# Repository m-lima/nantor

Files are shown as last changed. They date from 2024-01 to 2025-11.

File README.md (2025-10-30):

# Nantor

A wireless 42-key split keyboard made for Kailh Choc switches.

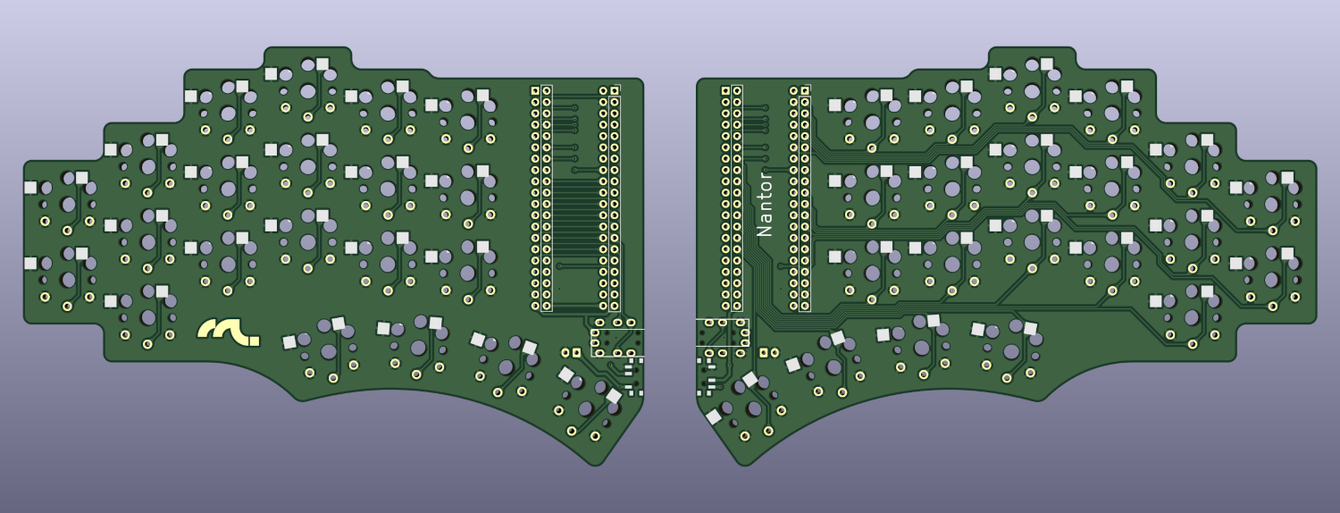
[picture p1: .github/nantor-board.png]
Nantor Board


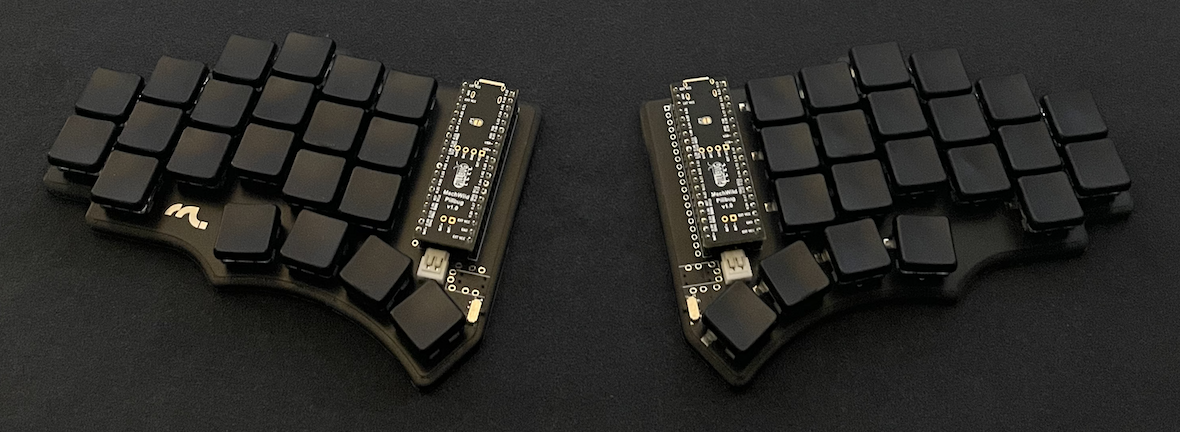
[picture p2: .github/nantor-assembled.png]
Nantor


**Features**

- Flippable design
- [PillBug] support
- [BlackPill] support
- Wired and wireless support
- Battery power support
- Hotswap switches support

## Hardware

The board was designed with [KiCad] and can be found in [board/kicad](board/kicad).

The gerber files can be found in [board/kicad/gerber](board/kicad/gerber).

## ZMK

For wireless and wired mode. This firmware assumes that [PillBug] is being used.

> [!TIP]
>
> This is the latest and recommended configuration.

### Layout

> [!NOTE]
>
> Definition available at [zmk/shared/config/boards/shields/nantor/nantor.keymap](zmk/shared/config/boards/shields/nantor/nantor.keymap)

#### Base (colemak)

```
            ╭───╮                     ╭───╮
        ╭───┤ F ├───┬───╮     ╭───┬───┤ U ├───╮
    ╭───┤ W ├───┤ P │ B │     │ J │ L ├───┤ Y ├───╮
╭───┤ Q ├───┤ S ├───┼───┤     ├───┼───┤ E ├───┤ ; ├───╮
│Esc├───┤ R ├───┤ T │ G │     │ M │ N ├───┤ I ├───┤ ' │
├───┤ A ├───┤ C ├───┼───┤     ├───┼───┤ , ├───┤ O ├───┤
│Alt├───┤ X ├───┤ D │ V │     │ K │ H ├───┤ . ├───┤ \ │
╰───┤ Z ├───┘   ╰───┴───╯     ╰───┴───╯   ╰───┤ / ├───╯
    ╰───╯     ╭───┬───╮         ╭───┬───╮     ╰───╯
          ╭───┤Spc│Sft├───╮ ╭───┤NUM│Ent├───╮
          │Bsp├───┴───┤ ⌘ │ │Ctl├───┴───┤FNS│
          ╰───╯       ╰───╯ ╰───╯       ╰───╯
```

#### Base (qwerty)

```
            ╭───╮                     ╭───╮
        ╭───┤ E ├───┬───╮     ╭───┬───┤ I ├───╮
    ╭───┤ W ├───┤ R │ T │     │ Y │ U ├───┤ O ├───╮
╭───┤ Q ├───┤ D ├───┼───┤     ├───┼───┤ K ├───┤ P ├───╮
│Esc├───┤ S ├───┤ F │ G │     │ H │ J ├───┤ L ├───┤ ' │
├───┤ A ├───┤ C ├───┼───┤     ├───┼───┤ , ├───┤ ; ├───┤
│Alt├───┤ X ├───┤ V │ B │     │ N │ M ├───┤ . ├───┤ \ │
╰───┤ Z ├───┘   ╰───┴───╯     ╰───┴───╯   ╰───┤ / ├───╯
    ╰───╯     ╭───┬───╮         ╭───┬───╮     ╰───╯
          ╭───┤Spc│Sft├───╮ ╭───┤NUM│Ent├───╮
          │Bsp├───┴───┤ ⌘ │ │Ctl├───┴───┤FNS│
          ╰───╯       ╰───╯ ╰───╯       ╰───╯
```

#### Numbers

```
            ╭───╮                     ╭───╮
        ╭───┤ 8 ├───┬───╮     ╭───┬───┤PUp├───╮
    ╭───┤ 7 ├───┤ 9 │ 0 │     │Hom│PDn├───┤End├───╮
╭───┤ = ├───┤ 5 ├───┼───┤     ├───┼───┤ ↑ ├───┤Sft├───╮
│Esc├───┤ 4 ├───┤ 6 │ [ │     │ ← │ ↓ ├───┤ → ├───┤Ctl│
├───┤ - ├───┤ 2 ├───┼───┤     ├───┼───┤ , ├───┤ ⌘ ├───┤
│Alt├───┤ 1 ├───┤ 3 │ ] │     │Del│Tab├───┤ . ├───┤Alt│
╰───┤ ` ├───┘   ╰───┴───╯     ╰───┴───╯   ╰───┤ / ├───╯
    ╰───╯     ╭───┬───╮         ╭───┬───╮     ╰───╯
          ╭───┤Spc│Sft├───╮ ╭───┤ ∆ │Ent├───╮
          │Bsp├───┴───┤ ⌘ │ │Ctl├───┴───┤CFG│
          ╰───╯       ╰───╯ ╰───╯       ╰───╯
```

#### Functions

```
            ╭───╮                     ╭───╮
        ╭───┤F10├───┬───╮     ╭───┬───┤+B ├───╮
    ╭───┤ F9├───┤F11│F12│     │   │-B ├───┤   ├───╮
╭───┤Ins├───┤ F6├───┼───┤     ├───┼───┤ ‖ ├───┤Sft├───╮
│Esc├───┤ F5├───┤ F7│ F8│     │   │ ◄ ├───┤ ► ├───┤Ctl│
├───┤Cap├───┤ F2├───┼───┤     ├───┼───┤ V0├───┤ ⌘ ├───┤
│Alt├───┤ F1├───┤ F3│ F4│     │   │-V ├───┤+V ├───┤Alt│
╰───┤PSc├───┘   ╰───┴───╯     ╰───┴───╯   ╰───┤   ├───╯
    ╰───╯     ╭───┬───╮         ╭───┬───╮     ╰───╯
          ╭───┤Spc│Sft├───╮ ╭───┤CFG│Ent├───╮
          │Bsp├───┴───┤ ⌘ │ │Ctl├───┴───┤ ∆ │
          ╰───╯       ╰───╯ ╰───╯       ╰───╯
```

#### Config

```
            ╭───╮                     ╭───╮
        ╭───┤   ├───┬───╮     ╭───┬───┤   ├───╮
    ╭───┤   ├───┤   │BTC│     │   │   ├───┤   ├───╮
╭───┤   ├───┤BT4├───┼───┤     ├───┼───┤   ├───┤   ├───╮
│   ├───┤BT3├───┤   │   │     │   │   ├───┤   ├───┤CLM│
├───┤BLE├───┤BT1├───┼───┤     ├───┼───┤   ├───┤   ├───┤
│   ├───┤BT0├───┤BT2│   │     │   │   ├───┤   ├───┤QWT│
╰───┤USB├───┘   ╰───┴───╯     ╰───┴───╯   ╰───┤   ├───╯
    ╰───╯     ╭───┬───╮         ╭───┬───╮     ╰───╯
          ╭───┤   │   ├───╮ ╭───┤ ∆ │ ᛒ ├───╮
          │   ├───┴───┤   │ │ ⌁ ├───┴───┤ ∆ │
          ╰───╯       ╰───╯ ╰───╯       ╰───╯
```

### LED encoding

> [!NOTE]
>
> This is assuming that the board being used is the PillBug (nRF52840)

> [!NOTE]
>
> In this section, a low frequency means a 500ms period, while high frequency means a 250ms period

#### Battery

If no charge is detected, all LEDs will blink at a low frequency.
Similarly, when at 100% charge, all LEDs will blink at a high frequency.
For all other values, the LEDs will encode the charge as such:

| Charge | Bottom | Center | Top  |
| --- | --- | --- | ---- |
| None | Low | Low | Low  |
| < 10%  | Low | Off | Off  |
| < 20%  | High | Off | Off  |
| < 30%  | Full | Off | Off  |
| < 40%  | Full | Low | Off  |
| < 50%  | Full | High | Off  |
| < 60%  | Full | Full | Off  |
| < 70%  | Full | Full | Low  |
| < 80%  | Full | Full | High |
| < 90%  | Full | Full | Full |
| > 90%  | High | High | High |

#### Bluetooth

The left side LEDs will encode the currently active channel in binary with the bottom LED being the least significant bit.
For a stable connection, the LEDs will stay fully on.
When open for connections, they will blink at a high frequency.
Lastly, when disconnected, they will blink at a low frequency.

### Flashing

> [!NOTE]
>
> This is assuming that the board being used is the PillBug (nRF52840)

1. [Build the images](#build-the-images)
2. [Enter UF2 mode](#enter-uf2-mode)
3. [Load the images](#load-the-images)

#### Build the images

```bash
$ ./zmk/build.sh make p
```

> [!NOTE]
>
> The above command will do a pristine build. Check [zmk/build.sh](zmk/build.sh) for more options.

The output files will be located at `zmk/shared/build/(left|right)/zephyr/zmk.uf2`.

#### Enter UF2 mode

1. Connect the USB cable
2. Reset twice. To reset, either press the reset button or pull the `RST` pin down to `GND`
3. The board should show up as a storage device

#### Load the images

The board should be available as a USB storage device. Copy the `zmk/shared/build/(left|right)/zephyr/zmk.uf2` files to this new device. It should flash and reset automatically.

## QMK

For wired mode. This firmware assumes that [BlackPill] is being used.

> [!WARNING]
>
> This is the first version of **Nantor** and is no longer actively maintained.

[PillBug]: https://mechwild.com/product/pillbug
[BlackPill]: https://stm32-base.org/boards/STM32F103C8T6-Black-Pill.html
[KiCad]: https://www.kicad.org

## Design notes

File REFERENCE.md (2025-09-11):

# References

## Documentation for pins on the Blackpill
[https://docs.qmk.fm/platformdev_blackpill_f4x1](https://docs.qmk.fm/platformdev_blackpill_f4x1)

## Reference for adding ZMK code

### RGB LED

[https://github.com/caksoylar/zmk-rgbled-widget](https://github.com/caksoylar/zmk-rgbled-widget)

### Leader key
[https://github.com/urob/zmk-leader-key](https://github.com/urob/zmk-leader-key)

### Module creation
[https://zmk.dev/docs/development/module-creation](https://zmk.dev/docs/development/module-creation)

### New behavior
[https://zmk.dev/docs/development/new-behavior](https://zmk.dev/docs/development/new-behavior)

### Device tree source syntax
[https://docs.zephyrproject.org/3.5.0/build/dts/bindings-syntax.html](https://docs.zephyrproject.org/3.5.0/build/dts/bindings-syntax.html)

### ZMK
[https://github.com/zmkfirmware/zmk](https://github.com/zmkfirmware/zmk)

### Zephyr
[https://github.com/zephyrproject-rtos/zephyr](https://github.com/zephyrproject-rtos/zephyr)

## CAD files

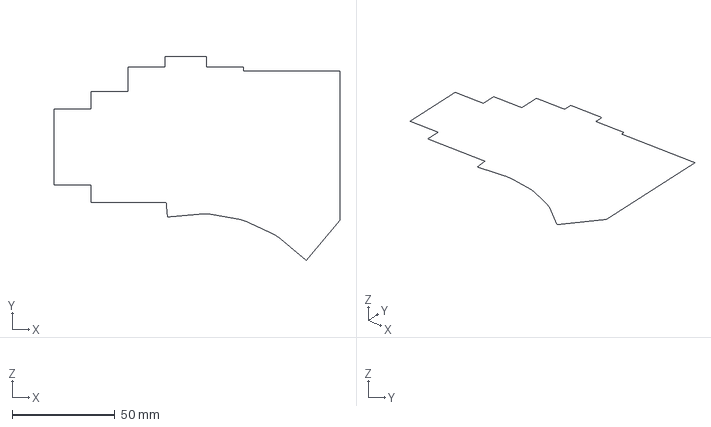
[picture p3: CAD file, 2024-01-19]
board/freecad/cadded.FCStd
139.0 x 99.1 x 0 mm

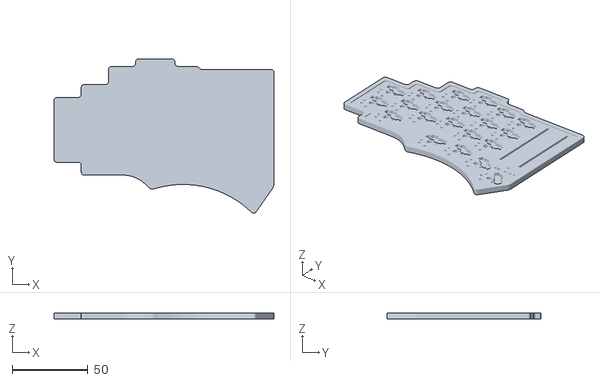
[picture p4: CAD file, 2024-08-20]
case/blender/case.stl
145.5 x 102.2 x 3.80

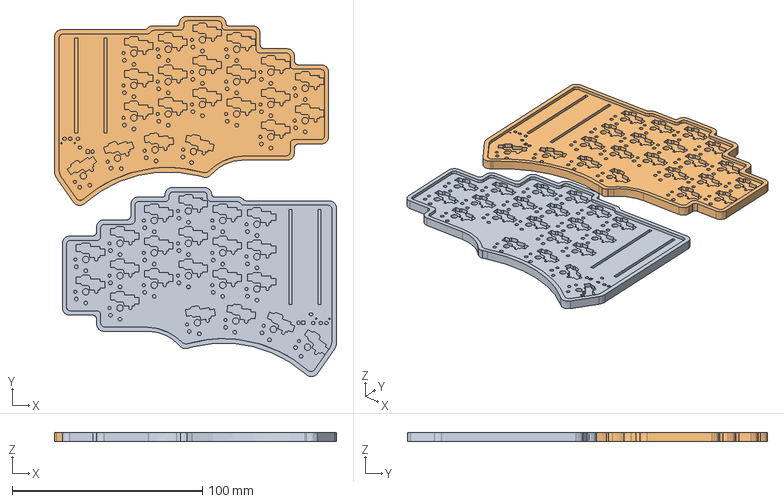
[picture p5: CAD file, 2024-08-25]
case/freecad/case_simple.FCStd
148.3 x 189.4 x 4.60 mm
left
right

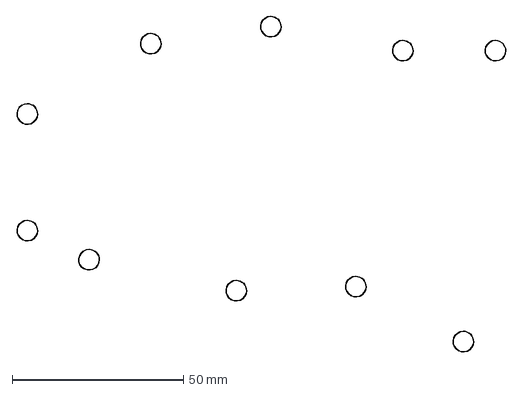
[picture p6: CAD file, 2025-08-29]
case/freecad/sources/v2/feet.dxf
142.8 x 98.1 mm

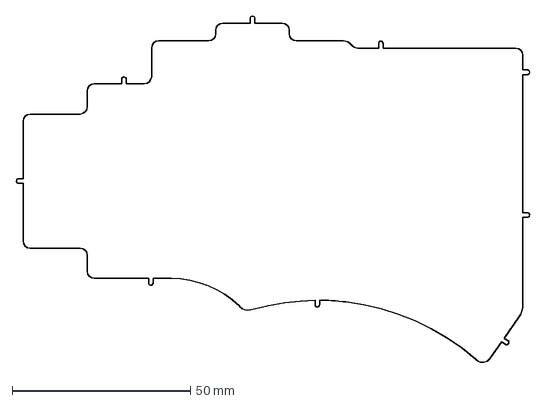
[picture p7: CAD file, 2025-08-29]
case/fusion/sources/walls.dxf
143.9 x 97.4 mm

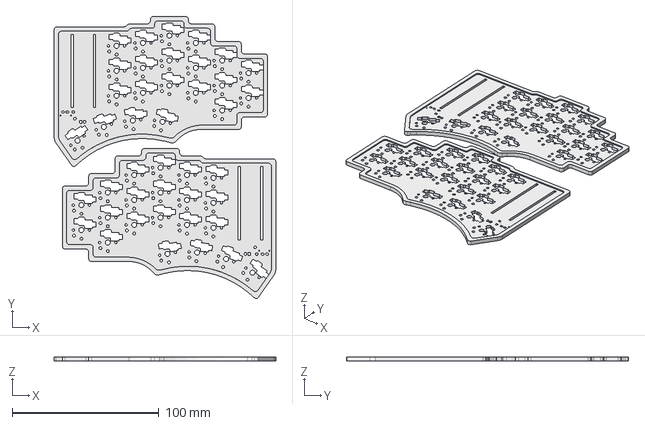
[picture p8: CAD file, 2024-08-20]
case/freecad/case_test.FCStd
151.1 x 192.2 x 2.80 mm

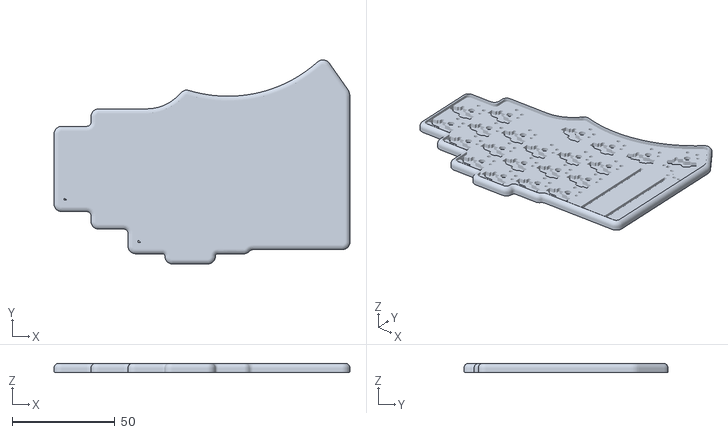
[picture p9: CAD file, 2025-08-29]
case/freecad/sources/v2/nantor_right.stl
144.1 x 99.4 x 4.60

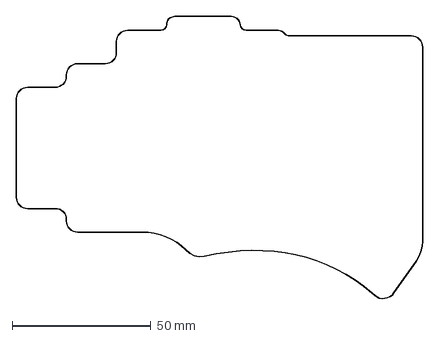
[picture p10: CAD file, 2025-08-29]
case/fusion/sources/case_base.dxf
146.1 x 101.8 mm

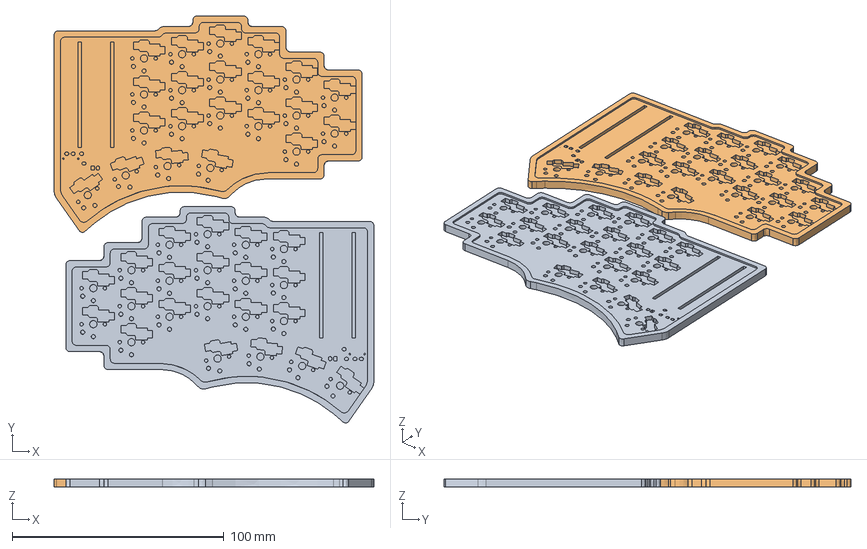
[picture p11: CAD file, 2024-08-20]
case/freecad/case.FCStd
151.1 x 192.2 x 3.80 mm
left
right (Mirror #1)

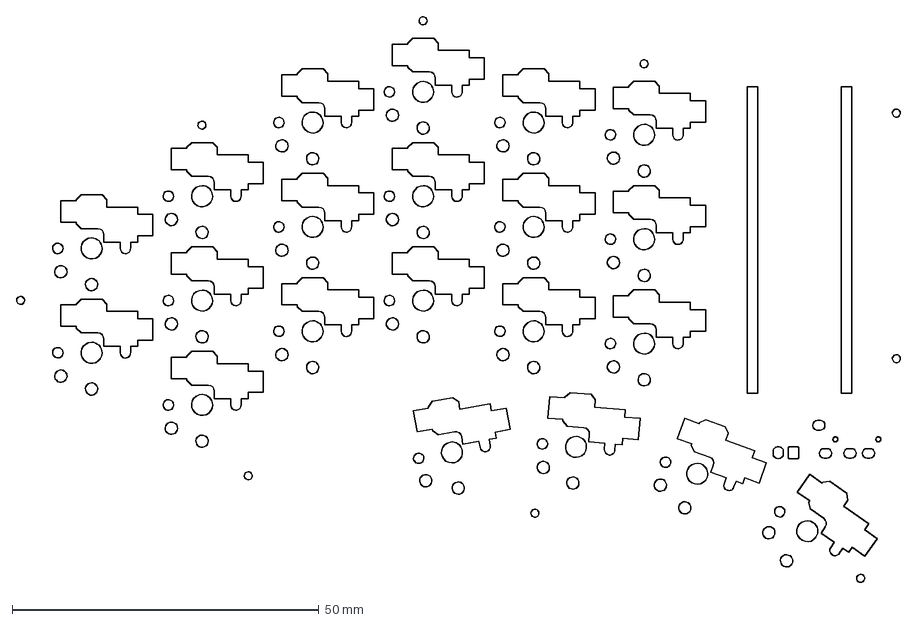
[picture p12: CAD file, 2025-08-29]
case/fusion/sources/wells_top_left.dxf
144.0 x 92.2 mm

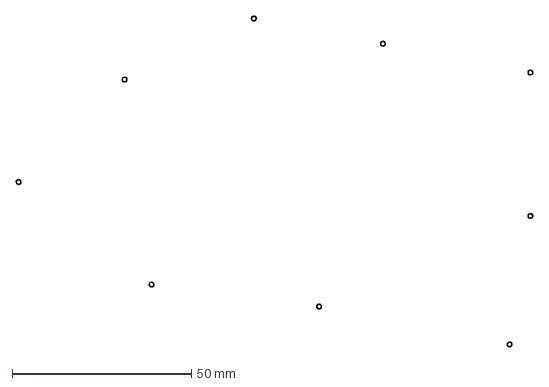
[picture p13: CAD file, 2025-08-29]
case/fusion/sources/holes_thru.dxf
144.0 x 92.2 mm

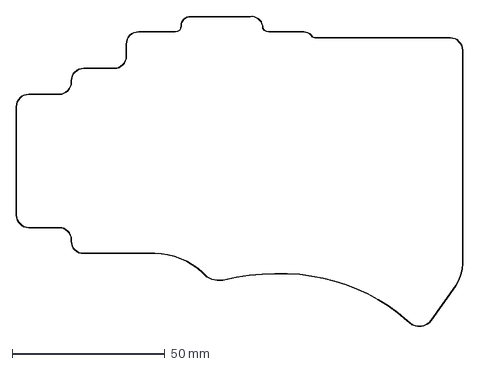
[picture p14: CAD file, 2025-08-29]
case/fusion/sources/case_base_line.dxf
146.1 x 101.8 mm

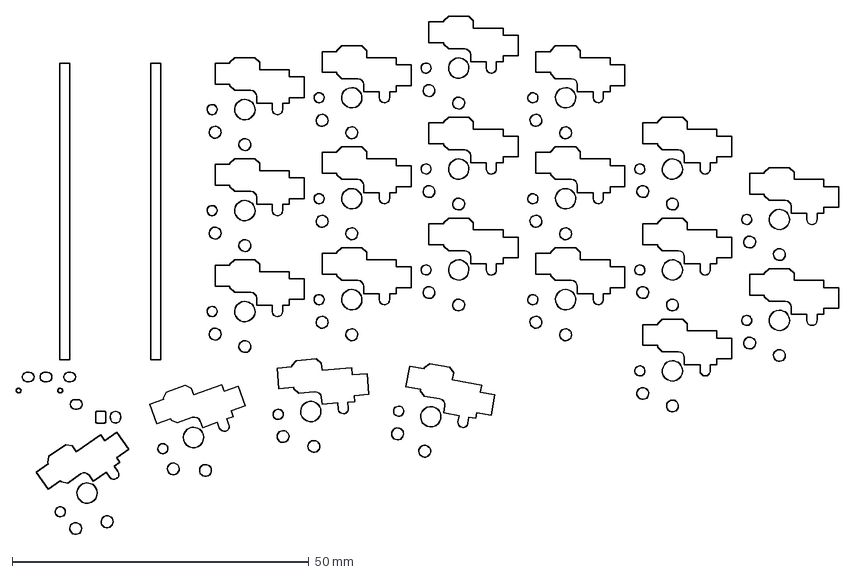
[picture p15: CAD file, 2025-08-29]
case/freecad/sources/v2/wells_right.dxf
138.5 x 87.3 mm

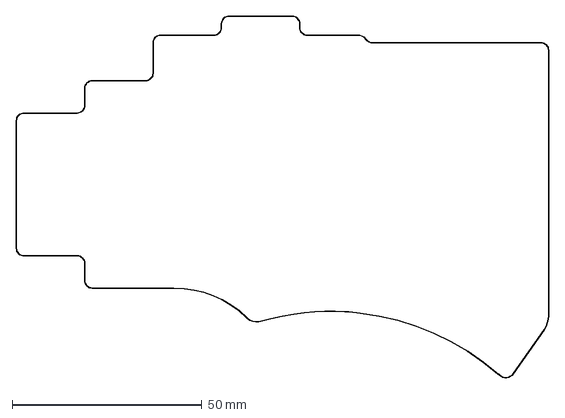
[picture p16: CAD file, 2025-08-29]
case/fusion/sources/case_hole.dxf
140.1 x 95.2 mm

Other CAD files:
case/freecad/sources/v2/nantor_left_tolerance.stl
case/freecad/sources/v2/nantor_right_tolerance.stl
case/freecad/sources/v2/nantor_left.stl
case/freecad/sources/v2/inner_bounds.dxf
case/freecad/sources/v2/bounds.dxf
case/freecad/sources/v2/feet_tolerance.dxf
case/freecad/sources/v2/inner_bounds_tolerance.dxf
case/freecad/sources/v2/inner_bounds_wire.dxf
case/freecad/sources/v2/nantor.stl
case/freecad/sources/v2/nantor_tolerance.stl
case/freecad/sources/v2/wells_left.dxf
case/fusion/nantor v3.f3d
case/fusion/nantor_tolerance v2.f3d
case/fusion/nantor_with_screws v2.f3d
case/fusion/sources/case_top.dxf
case/fusion/sources/hex.dxf
case/fusion/sources/wall_holes_bottom.dxf
case/fusion/sources/wells_bottom.dxf

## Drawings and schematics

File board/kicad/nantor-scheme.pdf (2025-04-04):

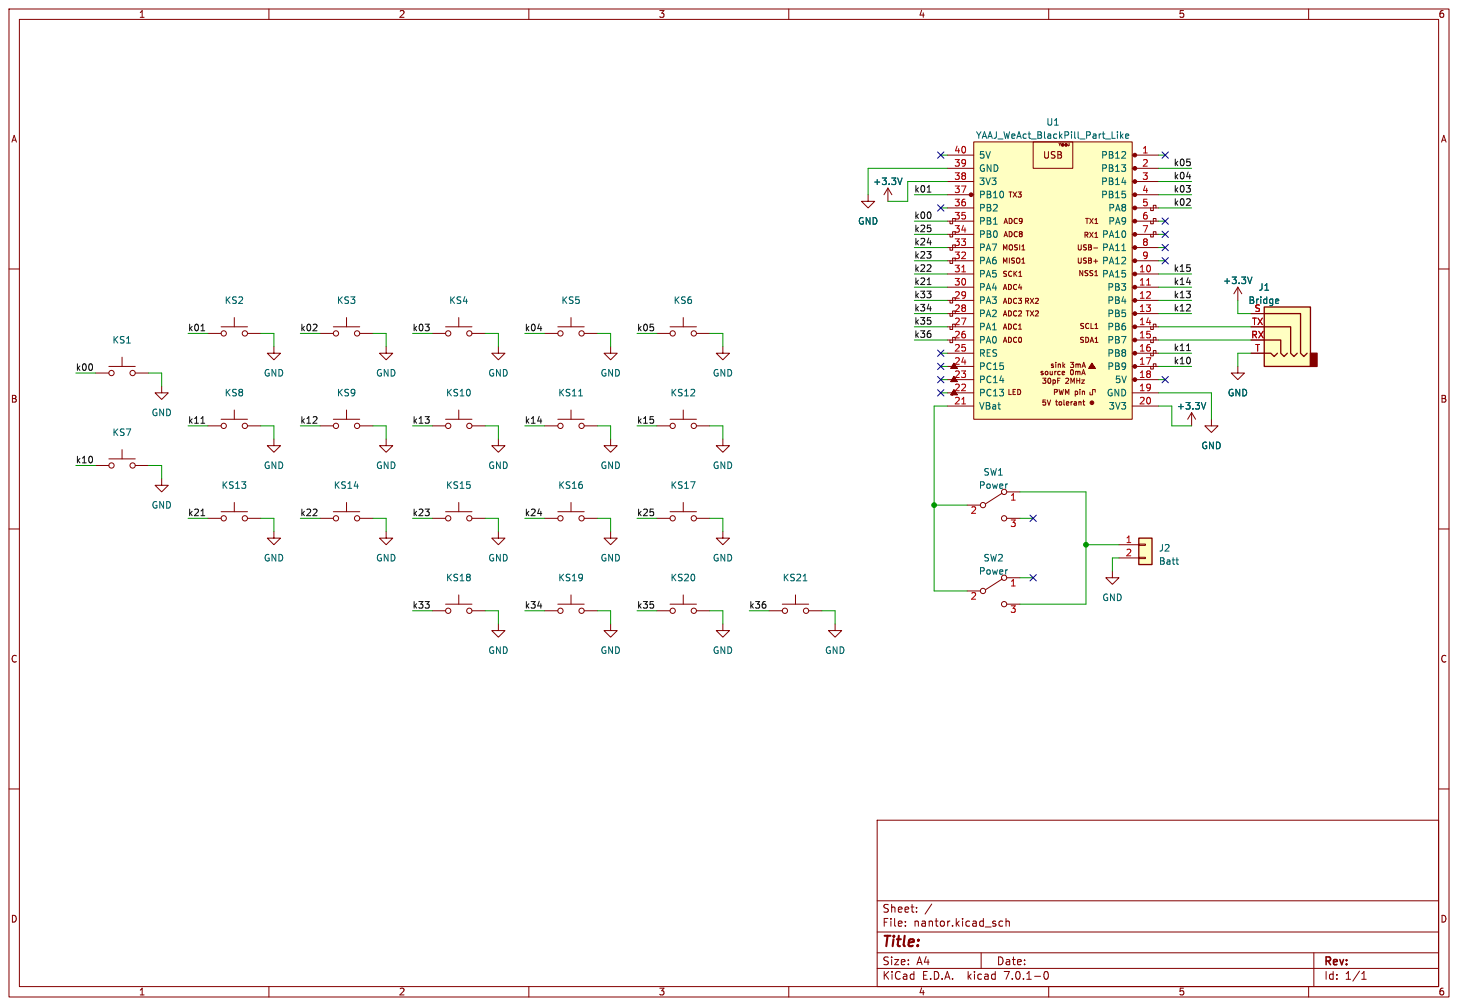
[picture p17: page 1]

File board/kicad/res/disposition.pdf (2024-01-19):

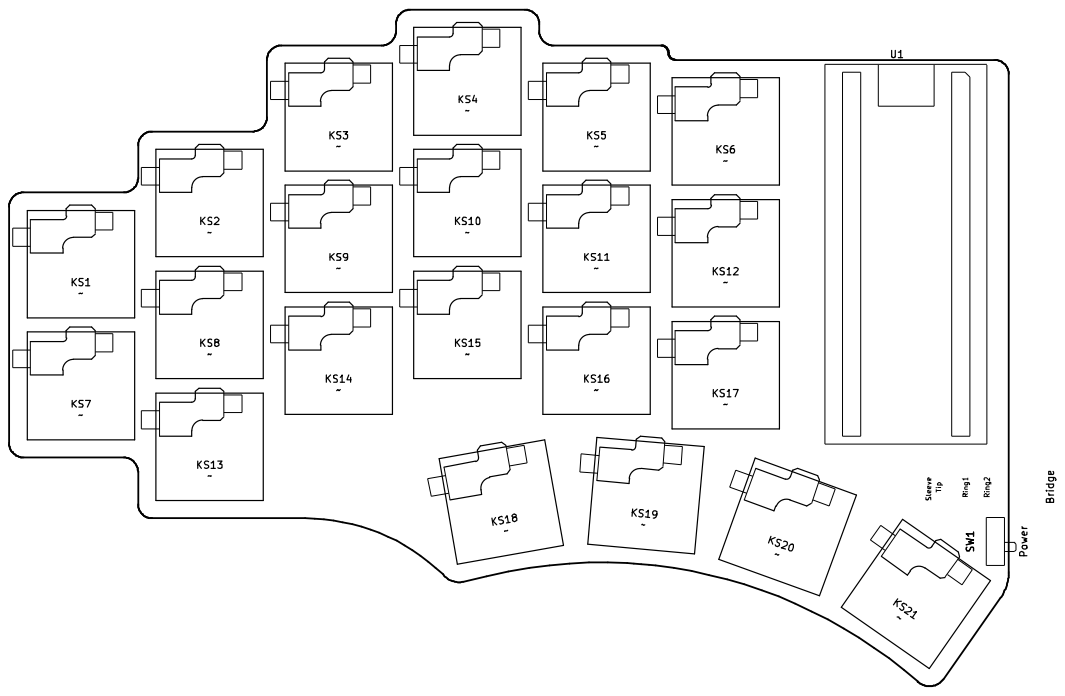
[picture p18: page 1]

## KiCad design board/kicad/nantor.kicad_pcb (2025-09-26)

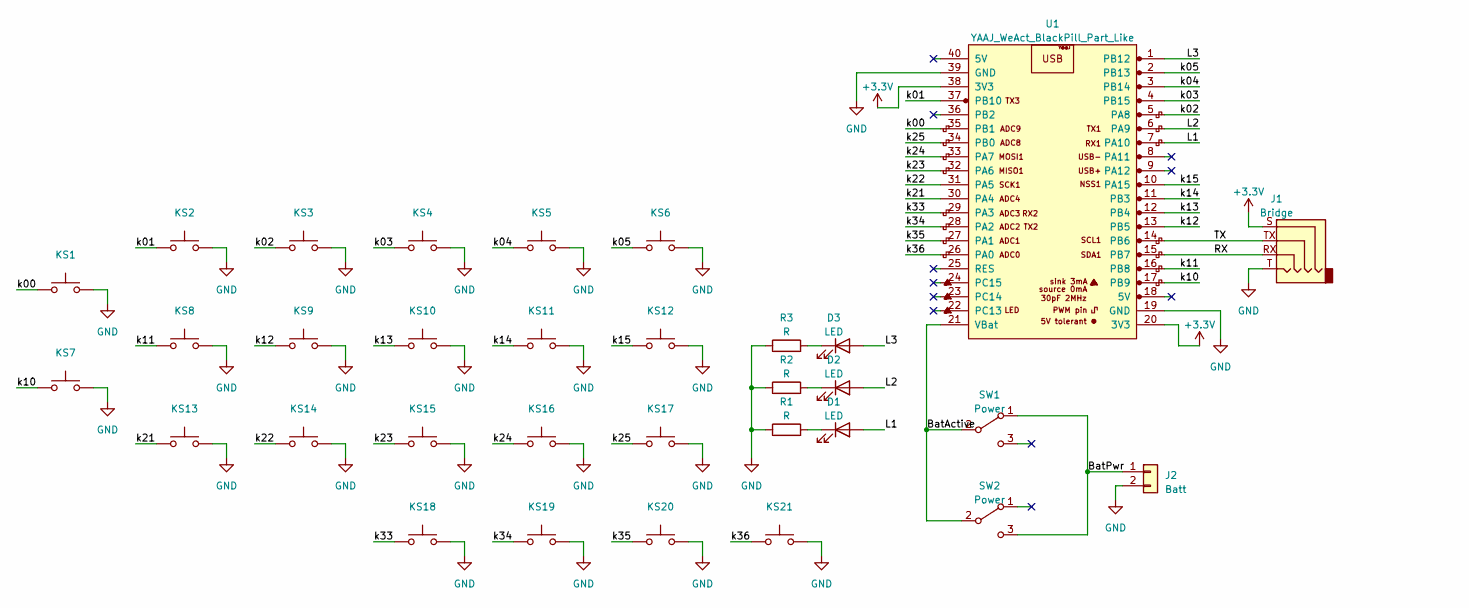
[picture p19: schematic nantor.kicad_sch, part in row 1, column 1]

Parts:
D1, D2, D3: LED; LED_0805
J1: Bridge; TRRS-PJ-320A
J2: Batt; JST_EH_S2B-EH_1x02_P2.50mm_Horizontal
KS1, KS2, KS3, KS4, KS5, KS6, KS7, KS8, KS9, KS10, KS11, KS12, KS13, KS14, KS15, KS16, KS17, KS18, KS19, KS20, KS21: Kailh_socket_PG1350_optional_reversible_clean
R1, R2, R3: R; LED_0805
SW1, SW2: Power; SW_SPDT_PCM12
U1: YAAJ_WeAct_BlackPill_Part_Like; BlackPill

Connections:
+3.3V: J1.S, U1.20 (3V3), U1.38 (3V3)
/BatActive: SW1.2 (B), SW2.2 (B), U1.21 (VBat)
/BatPwr: J2.1, SW1.1 (A), SW2.3 (C)
/L1: D1.2 (A), U1.7 (PA10)
/L2: D2.2 (A), U1.6 (PA9)
/L3: D3.2 (A), U1.1 (PB12)
/RX: J1.RX, U1.15 (PB7)
/TX: J1.TX, U1.14 (PB6)
/k00: KS1.1, U1.35 (PB1)
/k01: KS2.1, U1.37 (PB10)
/k02: KS3.1, U1.5 (PA8)
/k03: KS4.1, U1.4 (PB15)
/k04: KS5.1, U1.3 (PB14)
/k05: KS6.1, U1.2 (PB13)
/k10: KS7.1, U1.17 (PB9)
/k11: KS8.1, U1.16 (PB8)
/k12: KS9.1, U1.13 (PB5)
/k13: KS10.1, U1.12 (PB4)
/k14: KS11.1, U1.11 (PB3)
/k15: KS12.1, U1.10 (PA15)
/k21: KS13.1, U1.30 (PA4)
/k22: KS14.1, U1.31 (PA5)
/k23: KS15.1, U1.32 (PA6)
/k24: KS16.1, U1.33 (PA7)
/k25: KS17.1, U1.34 (PB0)
/k33: KS18.1, U1.29 (PA3)
/k34: KS19.1, U1.28 (PA2)
/k35: KS20.1, U1.27 (PA1)
/k36: KS21.1, U1.26 (PA0)
GND: J1.T, J2.2, KS1.2, KS2.2, KS3.2, KS4.2, KS5.2, KS6.2, KS7.2, KS8.2, KS9.2, KS10.2, KS11.2, KS12.2, KS13.2, KS14.2, KS15.2, KS16.2, KS17.2, KS18.2, KS19.2, KS20.2, KS21.2, R1.1, R2.1, R3.1, U1.19 (GND), U1.39 (GND)
unnamed: D1.1 (K), R1.2
unnamed: D2.1 (K), R2.2
unnamed: D3.1 (K), R3.2

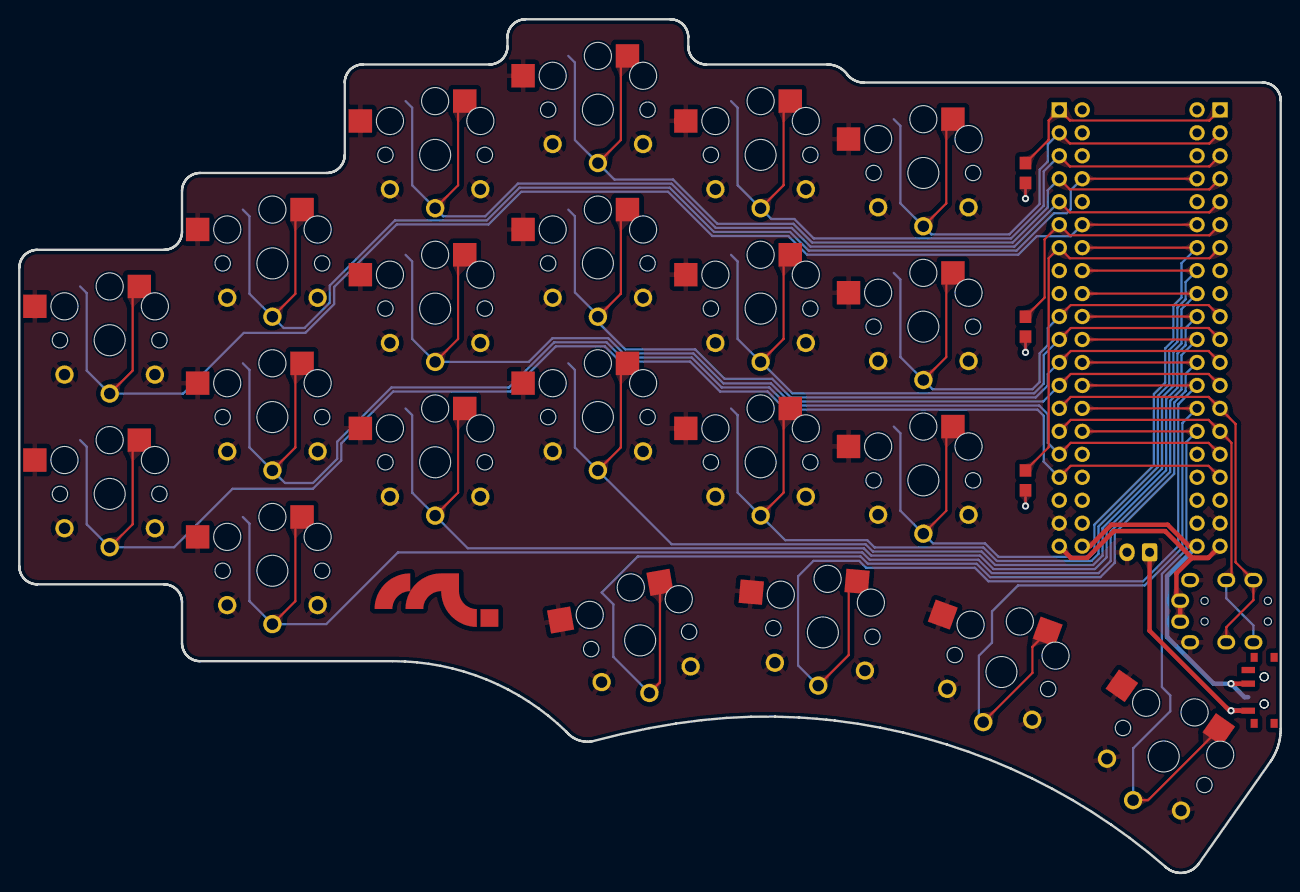
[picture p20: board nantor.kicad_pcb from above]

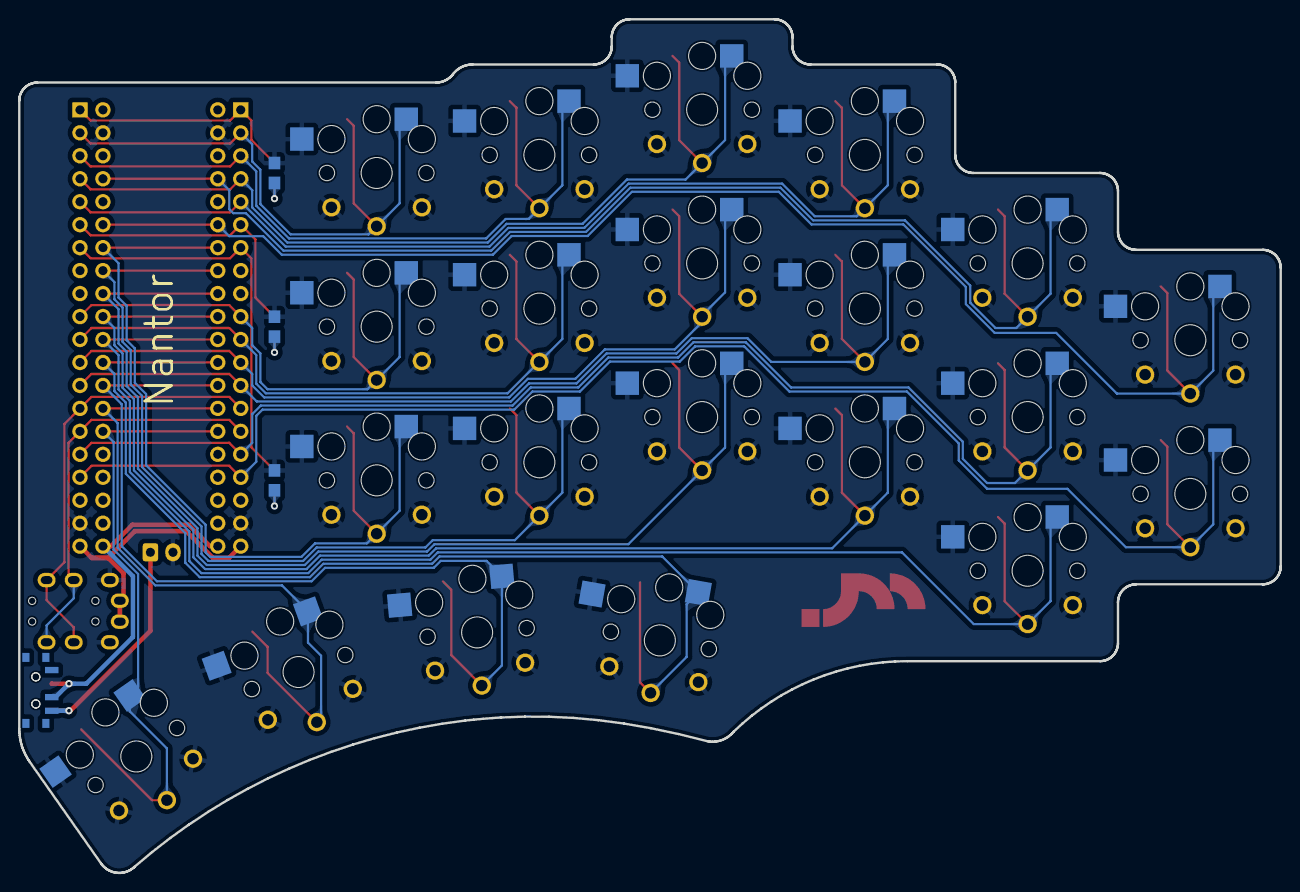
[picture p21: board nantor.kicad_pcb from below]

Board: 2 copper layers, 139.5 x 94.4 mm, 32 parts (5 on the bottom side), 33 nets.

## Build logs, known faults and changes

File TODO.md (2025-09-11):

# Board

- [x] Add LEDs
- [x] Move battery connector under the controller
- [x] Remove the decal from the TRRS
- [x] Fix ground on battery charger

# Case

- [ ] Add holes for balasts
- [ ] Update holes for new blueprint

# Repo

- [ ] Update README with new keybindings
- [ ] Update images
- [x] Update README and keymap with valid symbols

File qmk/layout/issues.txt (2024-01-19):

v*: Cannot cmd/ctrl/alt + tab while dragging
v[3-5]: Cmd + shift complicated

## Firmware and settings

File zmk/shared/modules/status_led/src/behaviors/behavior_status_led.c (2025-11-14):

#define DT_DRV_COMPAT zmk_behavior_status_led

#include <drivers/behavior.h>

#include <zephyr/device.h>
#include <zephyr/drivers/gpio.h>
#include <zephyr/logging/log.h>

#include <zmk/battery.h>
#include <zmk/behavior.h>
#include <zmk/ble.h>
#include <zmk/endpoints.h>
#include <zmk/event_manager.h>
#include <zmk/events/ble_active_profile_changed.h>
#include <zmk/events/split_peripheral_status_changed.h>
#include <zmk/split/bluetooth/peripheral.h>

#include <dt-bindings/zmk/stled.h>

#if DT_HAS_COMPAT_STATUS_OKAY(DT_DRV_COMPAT)

LOG_MODULE_REGISTER(status_led, CONFIG_ZMK_LOG_LEVEL);

/*
 * GPIO initialization
 */
BUILD_ASSERT(DT_NUM_INST_STATUS_OKAY(zmk_behavior_status_led) == 1,
             "Must have exactly one status-led behavior node");
#define NODE DT_INST(0, zmk_behavior_status_led)
#define LED_COUNT DT_PROP_LEN(NODE, led_gpios)
BUILD_ASSERT(
    LED_COUNT == 3,
    "Must have exactly three GPIO pins for the status-led behavior node");

static const struct gpio_dt_spec led_gpios[LED_COUNT] = {
    GPIO_DT_SPEC_GET_BY_IDX(NODE, led_gpios, 0),
    GPIO_DT_SPEC_GET_BY_IDX(NODE, led_gpios, 1),
    GPIO_DT_SPEC_GET_BY_IDX(NODE, led_gpios, 2),
};

/*
 * LED command definition
 */
typedef enum {
  OFF = 0,
  FULL = 1,
  LOW = 2,
  HIGH = 3,
} mode;

struct behavior_status_led_command {
  mode led0 : 2;
  mode led1 : 2;
  mode led2 : 2;
};

/*
 * LED command queue
 */

inline static void
make_channel_command(struct behavior_status_led_command *command, mode mode,
                     uint8_t channel) {
  command->led0 = (channel & 1 ? mode : OFF);
  command->led1 = (channel & 2 ? mode : OFF);
  command->led2 = (channel & 4 ? mode : OFF);
  LOG_DBG("Setting channel %d command to %d [%d %d %d]", channel, mode,
          command->led0, command->led1, command->led2);
}

inline static void
make_full_command(struct behavior_status_led_command *command, mode mode) {
  command->led0 = mode;
  command->led1 = mode;
  command->led2 = mode;
  LOG_DBG("Setting full command to %d [%d %d %d]", mode, command->led0,
          command->led1, command->led2);
}

K_MSGQ_DEFINE(behavior_status_led_msgq,
              sizeof(struct behavior_status_led_command), 4, 1);

BUILD_ASSERT(CONFIG_ZMK_BEHAVIOR_STATUS_LED_ROLLOVER > 0 &&
                 CONFIG_ZMK_BEHAVIOR_STATUS_LED_ROLLOVER < 8,
             "Rollover count must be between 1 and 7 inclusive");
#if CONFIG_ZMK_BEHAVIOR_STATUS_LED_ROLLOVER > 1
#define INVALID_COMMAND_IDX 128
struct behavior_status_led_command_queue_entry {
  struct zmk_behavior_binding_event event;
  struct behavior_status_led_command command;
};
static struct behavior_status_led_command_queue_entry
    command_queue[CONFIG_ZMK_BEHAVIOR_STATUS_LED_ROLLOVER];
static uint8_t rollover_count = 0;
inline static void send_command(struct zmk_behavior_binding_event *event,
                                struct behavior_status_led_command *command) {
  if (rollover_count == CONFIG_ZMK_BEHAVIOR_STATUS_LED_ROLLOVER) {
    uint8_t min_ts_idx = 0;
    int64_t min_ts = INT64_MAX;

    for (uint8_t i = 0; i < rollover_count; ++i) {
      if (command_queue[i].event.timestamp < min_ts) {
        min_ts_idx = i;
        min_ts = command_queue[i].event.timestamp;
      }
    }

    // If the min was not found, we default to removing the first one
    --rollover_count;
    command_queue[min_ts_idx] = command_queue[rollover_count];
  }
  command_queue[rollover_count] =
      (struct behavior_status_led_command_queue_entry){
          .event = *event,
          .command = {.led0 = command->led0,
                      .led1 = command->led1,
                      .led2 = command->led2}};
  ++rollover_count;
  LOG_DBG("Sending command [%d %d %d]", command->led0, command->led1,
          command->led2);
  k_msgq_put(&behavior_status_led_msgq, command, K_NO_WAIT);
}

inline static void clear(struct zmk_behavior_binding_event *event) {
  struct behavior_status_led_command command;

  if (rollover_count <= 1) {
    LOG_DBG("No command queue");
    rollover_count = 0;
    command = (struct behavior_status_led_command){
        .led0 = OFF,
        .led1 = OFF,
        .led2 = OFF,
    };
  } else {
    uint8_t clear_idx = INVALID_COMMAND_IDX;
    uint8_t max_ts_idx = INVALID_COMMAND_IDX;
    int64_t max_ts = INT64_MIN;

    for (uint8_t i = 0; i < rollover_count; ++i) {
      if (command_queue[i].event.layer == event->layer &&
          command_queue[i].event.position == event->position &&
          command_queue[i].event.source == event->source) {
        clear_idx = i;
      } else if (command_queue[i].event.timestamp > max_ts) {
        if (clear_idx >= 8) {
          clear_idx = max_ts_idx + 8;
        }
        max_ts_idx = i;
        max_ts = command_queue[i].event.timestamp;
      }
    }

    if (max_ts_idx == INVALID_COMMAND_IDX) {
      // Theoretically impossible
      LOG_DBG("No maximum timestamp. Clearing the queue");
      rollover_count = 0;
      command = (struct behavior_status_led_command){
          .led0 = OFF,
          .led1 = OFF,
          .led2 = OFF,
      };
    } else {
      if (clear_idx < 8) {
        LOG_DBG("Found command and next command in line");
        // Happy path: we found the command and a max
        command_queue[clear_idx] = command_queue[rollover_count - 1];
        command = command_queue[max_ts_idx].command;
      } else {
        // Did not find the command, delete the latest one
        command_queue[max_ts_idx] = command_queue[rollover_count - 1];

        // If we have a second largest, send that, else, clear
        if (clear_idx < 16) {
          LOG_DBG("Did not find the command. Deleting the max timestamp and "
                  "sending second largest");
          command = command_queue[clear_idx - 8].command;
        } else {
          LOG_DBG("Did not find the command. Deleting the max timestamp and "
                  "clearing");
          command = (struct behavior_status_led_command){
              .led0 = OFF,
              .led1 = OFF,
              .led2 = OFF,
          };
        }
      }
      --rollover_count;
    }
  }

  LOG_DBG("Sending command [%d %d %d]", command.led0, command.led1,
          command.led2);
  k_msgq_put(&behavior_status_led_msgq, &command, K_NO_WAIT);
}
#else
inline static void send_command(struct behavior_status_led_command *command) {
  LOG_DBG("Sending command [%d %d %d]", command->led0, command->led1,
          command->led2);
  k_msgq_put(&behavior_status_led_msgq, command, K_NO_WAIT);
}

inline static void clear() {
  struct behavior_status_led_command command = {
      .led0 = OFF,
      .led1 = OFF,
      .led2 = OFF,
  };
  LOG_DBG("Sending command [%d %d %d]", command.led0, command.led1,
          command.led2);
  k_msgq_put(&behavior_status_led_msgq, &command, K_NO_WAIT);
}
#endif // CONFIG_ZMK_BEHAVIOR_STATUS_LED_ROLLOVER > 1
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

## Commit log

2024-08-15 Add base for 3d printing
2024-08-16 Check that matches pcb
2024-08-17 Add board pdf
2024-08-17 Update case base
2024-08-20 Add freeCAD
    [case.FCStd, case_test.FCStd]
2024-08-20 Add stls
    [case.stl]
2024-08-24 Revamp case design
    Based on the first print, modifications to accommodate tolerances and
    get ready for screws
2024-08-24 Include schematics
2024-08-25 Make simpler case with no top
    [case_simple.FCStd]
2024-08-29 Reorg case vs board
    [case.FCStd, case.stl, case_simple.FCStd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]
2025-04-04 Make switch open
    [nantor.kicad_pcb, nantor.kicad_sch]
2025-04-04 Update outputs
    [nantor-B_Cu.gbr, nantor-B_Mask.gbr, nantor-B_Paste.gbr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]
2025-08-29 Add fusion stuff
    [bounds.dxf, case_base.dxf, case_base_line.dxf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]
2025-08-29 Remove silkscreens
    [nantor.kicad_pcb]
2025-08-29 Move battery connector
    [nantor.kicad_pcb]
2025-08-29 Add LEDs
    [nantor.kicad_pcb, nantor.kicad_sch]
2025-09-10 Reduce amount of vias
    [nantor.kicad_pcb]
2025-09-10 Increase ground plane
    [nantor.kicad_pcb]
2025-09-10 All should be a success flow
2025-09-11 Fix device tree source
    [behavior_status_led.c]
2025-09-11 Tighten the keyboard layout
2025-09-26 Print new version
    [nantor-B_Cu.gbl, nantor-B_Cu.gbr, nantor-B_Mask.gbs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]
2025-09-27 First prototype to upload
2025-09-27 Update pins to match the board
2025-10-30 Explain LEDs
